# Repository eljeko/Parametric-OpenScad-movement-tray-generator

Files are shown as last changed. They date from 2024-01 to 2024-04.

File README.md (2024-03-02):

# Parametric OpenScad Movement tray generator
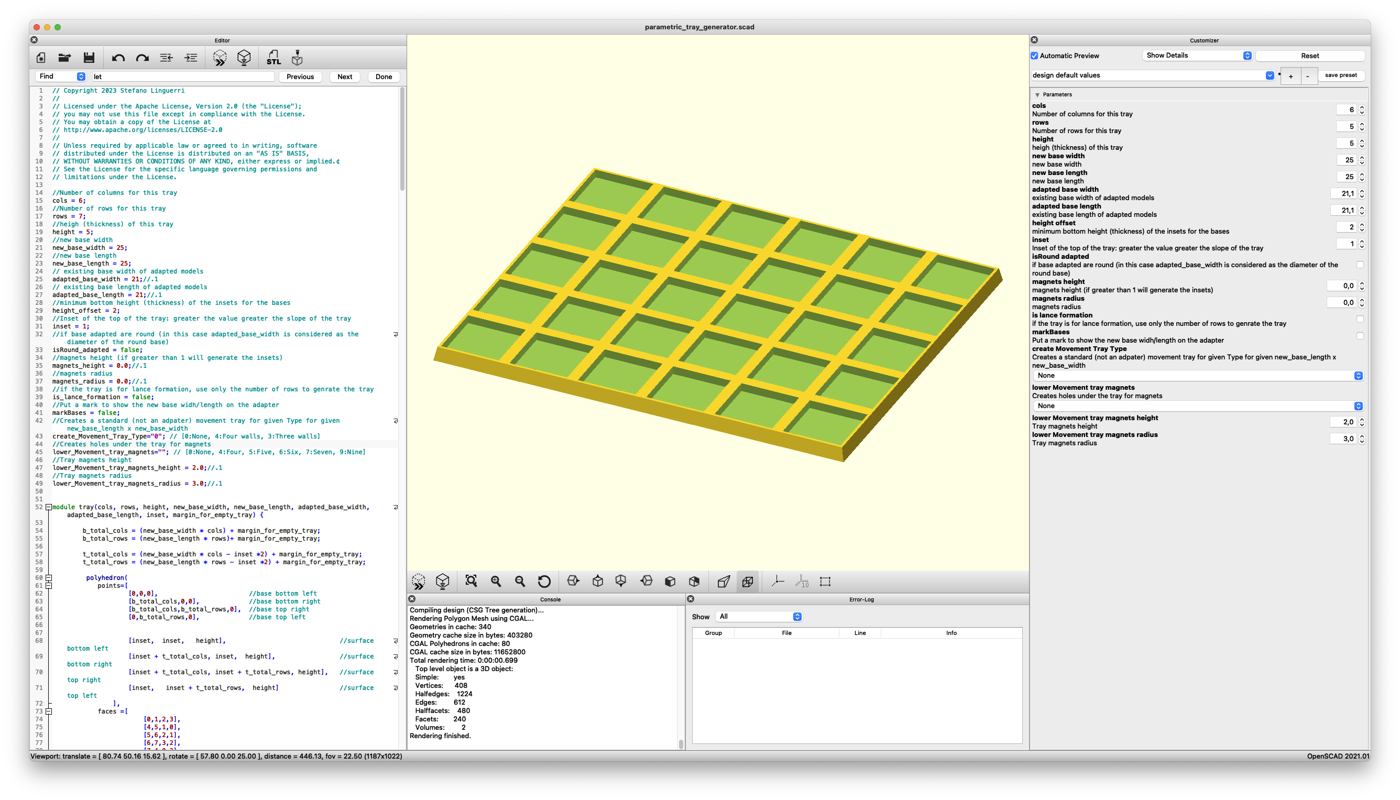
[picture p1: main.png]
Movement tray generator


This is an [OpenScad](http://openscad.org/index.html) script that can generate a movement tray to adapt the Old school warhammer 20mm square base to the new Old World 25mm square base system.

The script is absolutely parametric and can generate a custom tray for rows/cols tray.

I merged and enanched a new contribution with a script that can genrate bases plese follow the guide here [Parametric base generator](README_bases_generator.md)

# How to use

You can use the script and run it with [OpenScad](http://openscad.org/index.html) desktop app.

You can also generate trays from cli, for example this command:

```openscad -o tray.stl -D "cols=6;rows=3;" paremetric_tray_generator.scad```

Will generate a tray with 6 cols and 3 rows calculated for default 25mm square base and 20mm insets, the tray will be 150x75 mm.

The script can also generate a tray to adapt round bases setting ```isRound_adapted``` to true (default is false)

If you use different values for width and lenght you can generate also adapters for cavalry

# Important notes

## Tolerance 

When setting the value for ```adapted_base_width```and ```adapted_base_length``` add 1mm of tolerance eg: set 21mm for an old 20mm square base. The final "fit" depends also on you printer settings and calibration.  

### Parameters

```cols```  Number of columns for this tray

```rows``` Number of rows for this tray

```height``` heigh (thickness) of the tray

```new_base_width```  new base width 

```new_base_length```  new base length  

```adapted_base_width``` existing base width of adapted models

```adapted_base_length``` existing base length of adapted models

```height_offset``` minimum bottom height (thickness) of the insets for the bases

```inset``` Inset of the top of the tray: greater the value greater the slope of the tray

```isRound_adapted``` if base adapted are round (in this case adapted_base_size is considered as the diameter of the round base)

```magnets_height``` magnets height (if greater than zero will generate the insets)

```magnets_radius``` magnets radius

```isLanceFormation``` if the tray is for lance formation, use only the number of ```rows``` to genrate the tray

```createEmptyMovementTray``` Create a standard (non an adpater) movement tray for given new_base_length x new_base_width

```markBases``` Put a mark to show the new base widh/length on the adapter

## What you can do with the script

[Here](parametric_tray_generator.json) you can find a paremetric saved profiles file for openscad: place it in the same folder where you use the script, then you should see a list of profiles:

<img src="profiles.png" alt= profiles width="400" >

### Square 20mm to 25mm sample:

<img src="sample_tray.png" alt= “square” width="400" >

### Round 25mm to 25mm sample:

<img src="main_round_02.png" alt= “round” width="600" >

### Rectangular 25x50mm to 30x60mm sample:

<img src="rectangular.png" alt= “cavalry” width="600" >

### Adapter with marked bases to identify better minis contact in combat

<img src="marked_base.png" alt="marked_base" width="600" >

<img src="marked_base_02.png" alt="marked_base_02" width="600" >

### Holed tray

This is particularly useful to glue a metal plate under the tray to use magnetized minis

To obtain it just use a negative number for ```height_offset``` like -1

<img src="holed.png" alt=“holed” width="600" >

### Magnets 3x1mm insets

<img src="magnets.png" alt= “magnets” width="600" >

### Lance Formation

<img src="lance.png" alt= “lance” width="600" >

### Empty standard movement tray

With 3 walls

<img src="empty.png" alt= “standardmovement” width="600" >

With 4 walls

<img src="empty_4_walls.png" alt= “standardmovement” width="600" >

### Empty standard Lance movement tray

With 3 walls

<img src="lance_movement_standard.png" alt="lance_movement_standard" width="600" >

With 4 walls

<img src="empty_lance_4_walls.png" alt="lance_movement_standard" width="600" >

### Magnetized Tray (support for 4,5,7,9 magnets)

With ```lower_Movement_tray_magnets``` you can set the number of magnets holes to magnetize your tray/adapter for transportation

<img src="lower_magnets_5.png" alt="lower_magnets_5" width="600" >

<img src="lower_magnets_9.png" alt="lower_magnets_9" width="600" >

### One mini adapter

This example shows how to setup a single base adapter (remeber to add tolerance acconrding to your printer settings)

<img src="one_base_cavalry.png" alt="one_base_cavalry" width="600" >

## License

Parametric OpenScad movement tray generator is under [Apache 2
license](http://www.apache.org/licenses/LICENSE-2.0.html).

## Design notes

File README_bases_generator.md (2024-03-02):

# Parametric OpenScad Bases generator
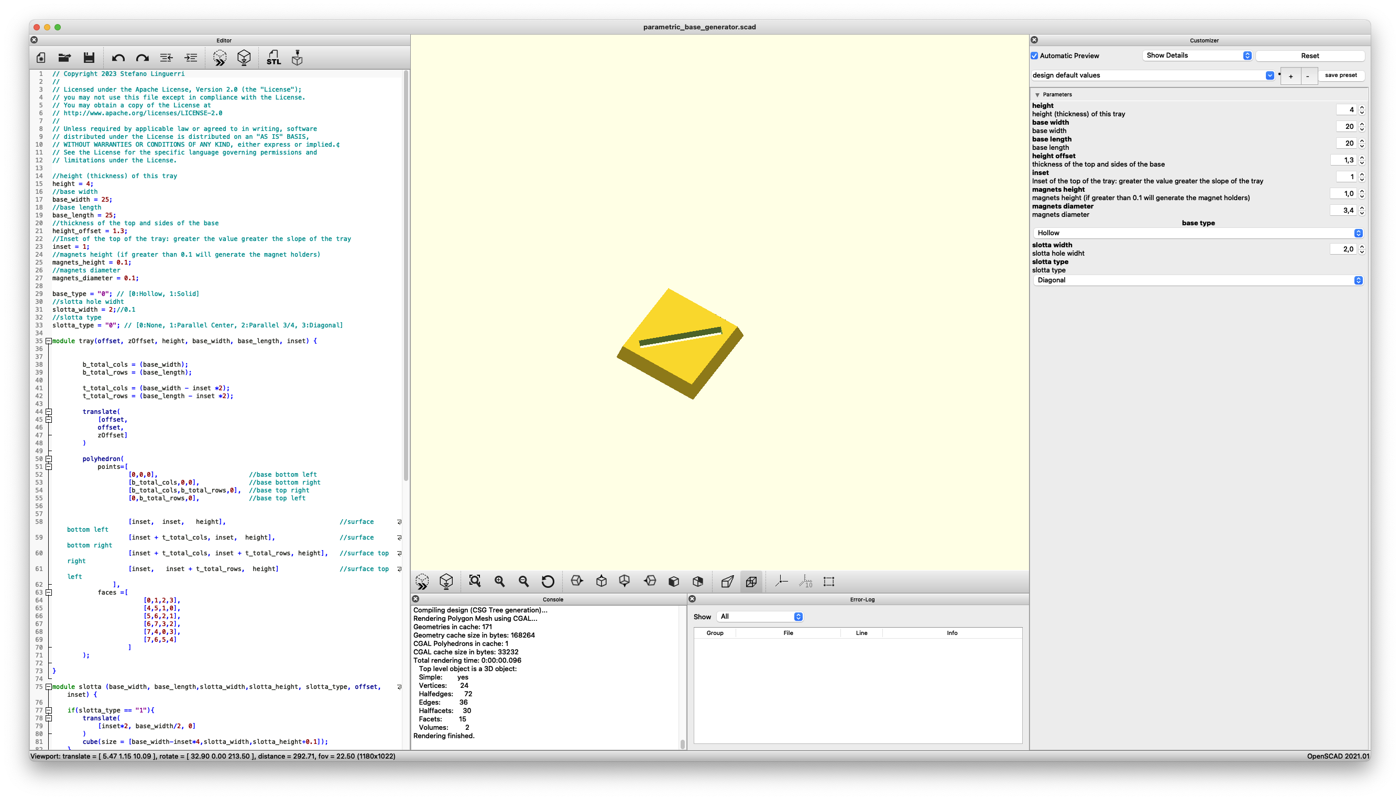
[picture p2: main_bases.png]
Bases generator


This is an [OpenScad](http://openscad.org/index.html) script that can generate square bases for Old school warhammer base system.

The script is absolutely parametric and can generate a custom square bases of any size (hollowed or solid) with slotta hole.

# Parameters

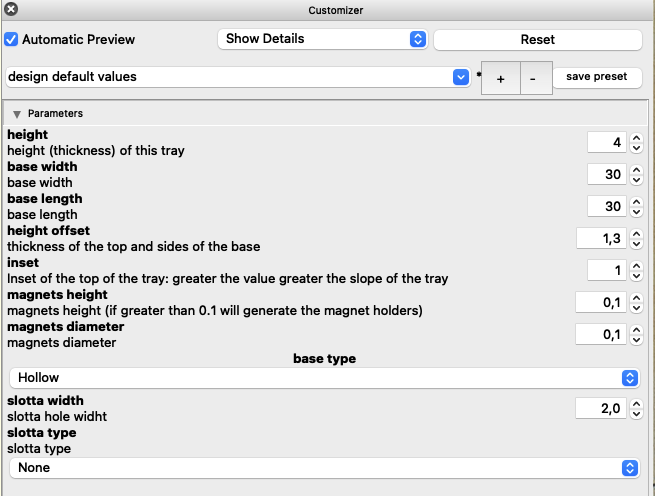
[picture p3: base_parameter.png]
parameter


## Some example 

Slotta

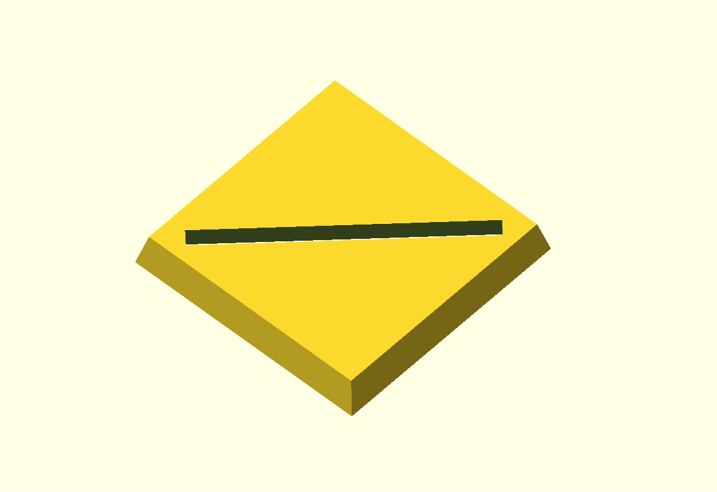
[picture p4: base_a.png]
base_a

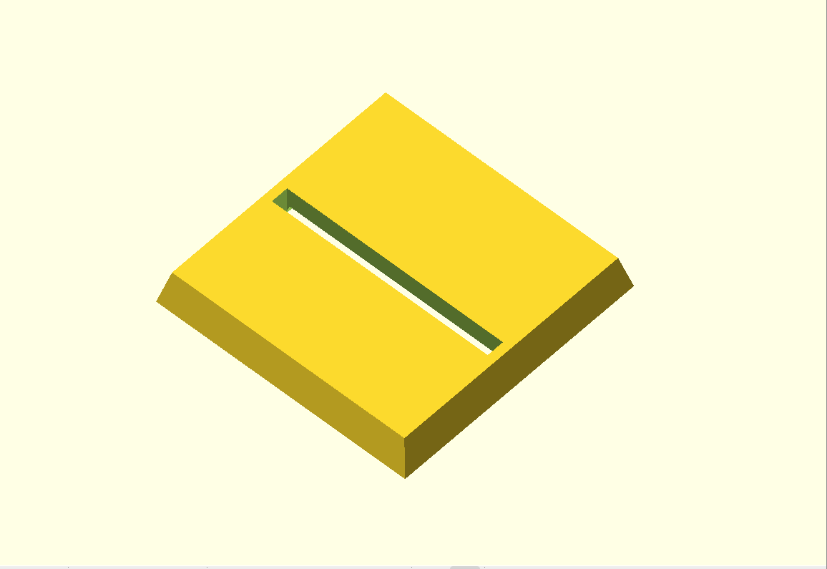
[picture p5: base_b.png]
base_b

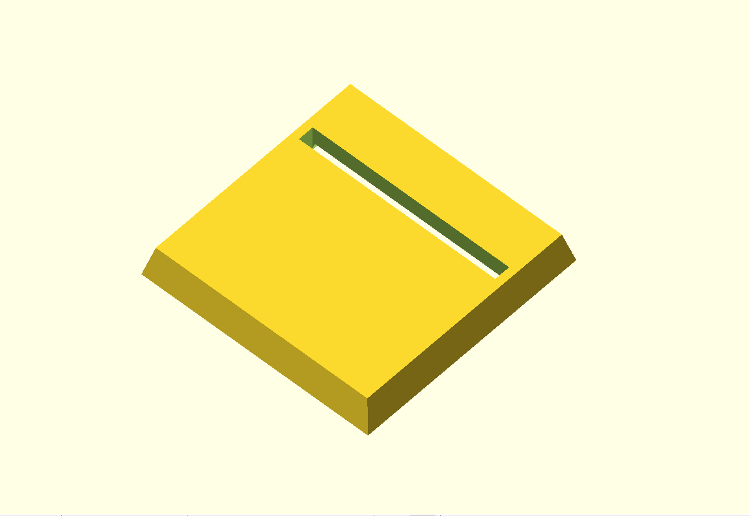
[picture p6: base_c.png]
base_c


Plain

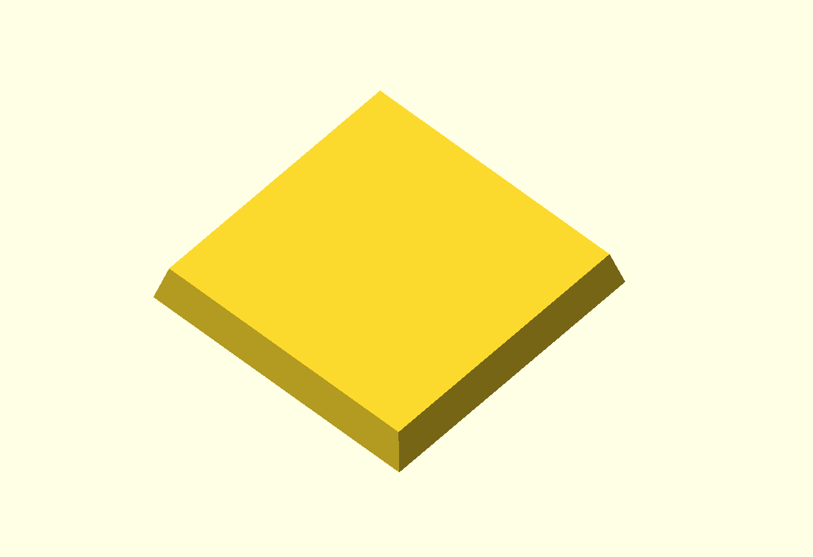
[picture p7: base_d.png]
base_d


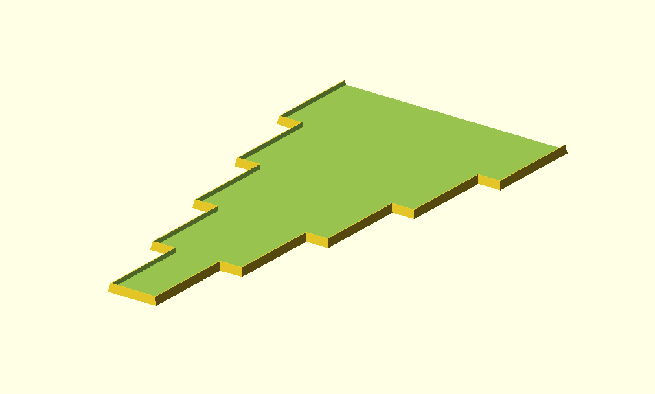
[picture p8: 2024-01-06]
lance_movement_standard.png

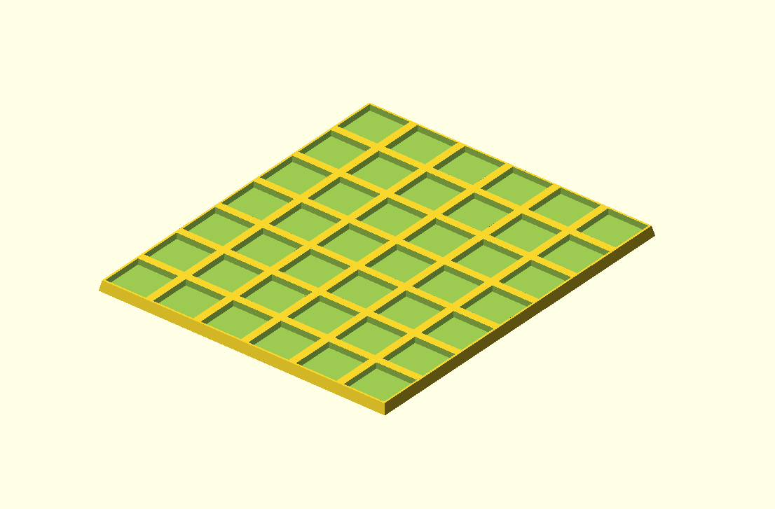
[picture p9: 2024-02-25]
sample_tray.png

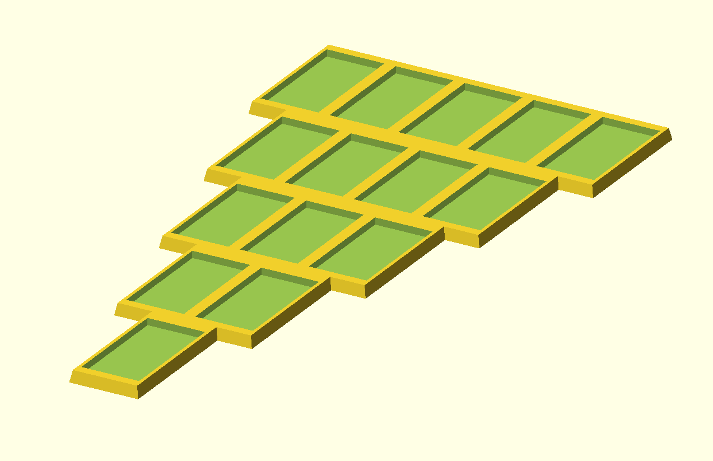
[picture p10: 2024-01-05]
lance.png

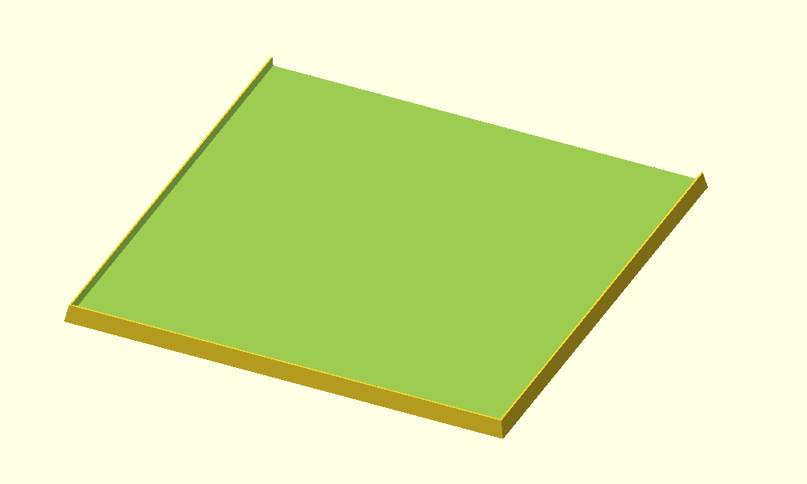
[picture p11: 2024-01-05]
empty.png

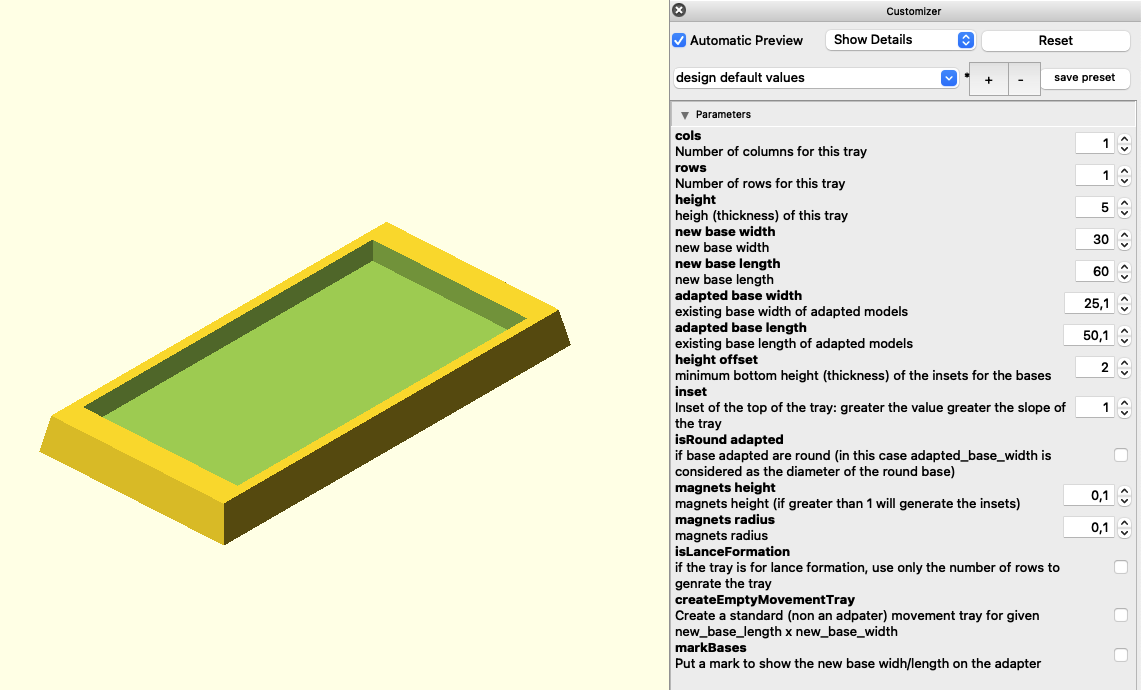
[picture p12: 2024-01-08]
one_base_cavalry.png

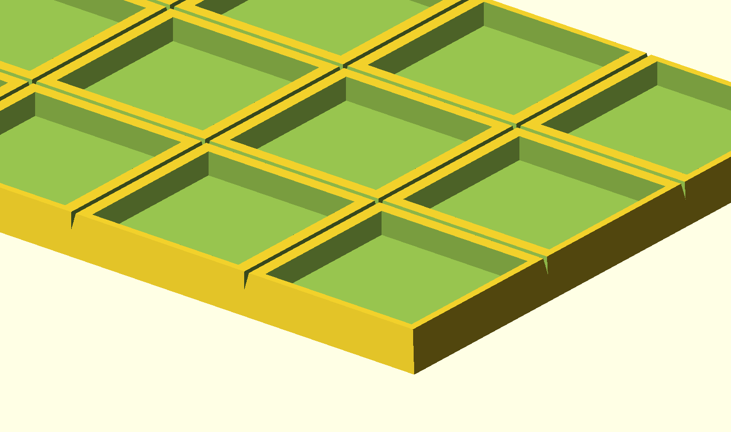
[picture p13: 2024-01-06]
marked_base_02.png

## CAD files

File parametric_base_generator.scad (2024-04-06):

// Copyright 2023 Stefano Linguerri
//
// Licensed under the Apache License, Version 2.0 (the "License");
// you may not use this file except in compliance with the License.
// You may obtain a copy of the License at
// http://www.apache.org/licenses/LICENSE-2.0
//
// Unless required by applicable law or agreed to in writing, software
// distributed under the License is distributed on an "AS IS" BASIS,
// WITHOUT WARRANTIES OR CONDITIONS OF ANY KIND, either express or implied.¢
// See the License for the specific language governing permissions and
// limitations under the License.

//height (thickness) of this tray
height = 4;//0.1
//base width 
base_width = 25;
//base length 
base_length = 25;
//thickness of the top and sides of the base
height_offset = 1.3;
//Inset of the top of the tray: greater the value greater the slope of the tray
inset = 1;
//magnets height (if greater than 0.1 will generate the magnet holders)
magnets_height = 0.1;
//magnets diameter
magnets_diameter = 0.1;

base_type = "0"; // [0:Hollow, 1:Solid]
//slotta hole width
slotta_width = 2;//0.1
//slotta hole length
slotta_length = 18;//0.1
//slotta type
slotta_type = "0"; // [0:None, 1:Parallel Center, 2:Parallel 3/4, 3:Diagonal]

module tray(offset, zOffset, height, base_width, base_length, inset) {
    
        
        b_total_cols = (base_width);
        b_total_rows = (base_length);
        
        t_total_cols = (base_width - inset *2);
        t_total_rows = (base_length - inset *2);
    
        translate(
            [offset,
            offset,
            zOffset]
        )

        polyhedron(
            points=[
                    [0,0,0],                        //base bottom left
                    [b_total_cols,0,0],             //base bottom right
                    [b_total_cols,b_total_rows,0],  //base top right
                    [0,b_total_rows,0],             //base top left


                    [inset,  inset,   height],                              //surface bottom left
                    [inset + t_total_cols, inset,  height],                 //surface bottom right
                    [inset + t_total_cols, inset + t_total_rows, height],   //surface top right
                    [inset,   inset + t_total_rows,  height]                //surface top left
                ],
            faces =[
                        [0,1,2,3],
                        [4,5,1,0],
                        [5,6,2,1],
                        [6,7,3,2],
                        [7,4,0,3],
                        [7,6,5,4]
                    ]
        ); 
           
}

module slotta (base_width, base_length,slotta_width,slotta_height, slotta_type, offset,inset) {   

    if(slotta_type == "1"){
        translate( 
            [(base_width - slotta_length)/2, base_width/2, -0.1]
        )
        cube(size = [slotta_length,slotta_width,slotta_height+0.2]);
    }
    
    if(slotta_type == "2"){
        translate( 
            [(base_width - slotta_length)/2, base_width/4, -0.1]
        )
        cube(size = [slotta_length,slotta_width,slotta_height+0.2]);
    }
    
    if(slotta_type == "3"){

        let(cathetus_slotta_width = slotta_width/sqrt(2),cathetus_slotta_lenght = slotta_length/sqrt(2)){
            echo(">>>>",cathetus_slotta_lenght)
            translate( 
                [(base_width/2)-(cathetus_slotta_lenght/2), (base_length/2) -(cathetus_slotta_lenght/2), -0.1]
            )

            rotate(45)

            cube(size = [slotta_length,slotta_width,slotta_height+0.2]);
                    
        }
    }    
}

module magnets_holes (base_width, base_length, magnets_height, magnets_diameter) {   
    translate( 
        [base_width/2,
        base_length/2, 
        -0.1]
    )
    cylinder(d = magnets_diameter, h = magnets_height+0.01,$fn=30);
}

difference(){  
    
    color ([0.5, 0.5, 0.5]) {
        tray(0,0, height, base_width, base_length, inset);
    }
    
    if(base_type == "0"){
        color ([0.7, 0.7, 0.7]) {                   
            tray(height_offset, -1.0, height - height_offset, base_width - (2*height_offset), base_length - (2 * height_offset), inset);
        }   
    }
    
    if (magnets_height > 0.1){     
        magnets_holes (base_width, base_length, magnets_height, magnets_diameter);            
    }
    
    slotta(base_width,base_length,slotta_width,height,slotta_type,height_offset,inset);

}

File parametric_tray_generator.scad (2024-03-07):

// Copyright 2023 Stefano Linguerri
//
// Licensed under the Apache License, Version 2.0 (the "License");
// you may not use this file except in compliance with the License.
// You may obtain a copy of the License at
// http://www.apache.org/licenses/LICENSE-2.0
//
// Unless required by applicable law or agreed to in writing, software
// distributed under the License is distributed on an "AS IS" BASIS,
// WITHOUT WARRANTIES OR CONDITIONS OF ANY KIND, either express or implied.¢
// See the License for the specific language governing permissions and
// limitations under the License.

//Number of columns for this tray
cols = 6;
//Number of rows for this tray
rows = 7;
//heigh (thickness) of this tray
height = 5;//.1
//new base width 
new_base_width = 25;
//new base length 
new_base_length = 25;
// existing base width of adapted models
adapted_base_width = 21;//.1
// existing base length of adapted models
adapted_base_length = 21;//.1
//minimum bottom height (thickness) of the insets for the bases
height_offset = 2;
//Inset of the top of the tray: greater the value greater the slope of the tray
inset = 1;
//if base adapted are round (in this case adapted_base_width is considered as the diameter of the round base)
isRound_adapted = false;
//magnets height (if greater than 1 will generate the insets)
magnets_height = 0.0;//.1
//magnets radius
magnets_radius = 0.0;//.1
//if the tray is for lance formation, use only the number of rows to genrate the tray
is_lance_formation = false;
//Put a mark to show the new base widh/length on the adapter
markBases = false;
//Creates a standard (not an adpater) movement tray for given Type for given new_base_length x new_base_width 
create_Movement_Tray_Type="0"; // [0:None, 4:Four walls, 3:Three walls]
//Creates holes under the tray for magnets
lower_Movement_tray_magnets="0"; // [0:None, 4:Four, 5:Five, 6:Six, 7:Seven, 9:Nine]
//Tray magnets height
lower_Movement_tray_magnets_height = 2.0;//.1
//Tray magnets radius
lower_Movement_tray_magnets_radius = 3.0;//.1


module tray(cols, rows, height, new_base_width, new_base_length, adapted_base_width, adapted_base_length, inset, margin_for_empty_tray) {
    
        b_total_cols = (new_base_width * cols) + margin_for_empty_tray;
        b_total_rows = (new_base_length * rows)+ margin_for_empty_tray;
        
        t_total_cols = (new_base_width * cols - inset *2) + margin_for_empty_tray;
        t_total_rows = (new_base_length * rows - inset *2) + margin_for_empty_tray;
        
         polyhedron(
            points=[
                    [0,0,0],                        //base bottom left
                    [b_total_cols,0,0],             //base bottom right
                    [b_total_cols,b_total_rows,0],  //base top right
                    [0,b_total_rows,0],             //base top left
        

                    [inset,  inset,   height],                              //surface bottom left
                    [inset + t_total_cols, inset,  height],                 //surface bottom right
                    [inset + t_total_cols, inset + t_total_rows, height],   //surface top right
                    [inset,   inset + t_total_rows,  height]                //surface top left
                ],
            faces =[
                        [0,1,2,3],
                        [4,5,1,0],
                        [5,6,2,1],
                        [6,7,3,2],
                        [7,4,0,3],
                        [7,6,5,4]
                    ]
        ); 
   
}

//this module will create the hole in the "empty" classic movement tray
module empty_tray_hole(cols, rows, height_offset, new_base_width,  new_base_length, adapted_base_width, adapted_base_length, inset, margin_for_empty_tray,create_Movement_Tray_Type) {
    
    t_total_cols = (new_base_width * cols ) ;
    t_total_rows = (new_base_length * rows);

 
    translate( 
                [margin_for_empty_tray/2, //row
               margin_for_empty_tray/2, //col
                height_offset]
    )                       

    if(create_Movement_Tray_Type == "3"){
        cube([t_total_cols,t_total_rows+margin_for_empty_tray, 30]);            
    }else{
        cube([t_total_cols,t_total_rows, 30]);            
    }    
}

module adapted_base_holes(cols, rows, height_offset, new_base_width,  new_base_length, adapted_base_width, adapted_base_length) {
    
    gap_w = new_base_width - adapted_base_width;
    gap_l = new_base_length - adapted_base_length;

    for (c = [0:cols-1]){
        for (r = [0:rows-1]){
           translate( 
                        [gap_w/2 + (c*adapted_base_width) + (c*gap_w), //row
                        gap_l/2 + (r*adapted_base_length) + (r*gap_l), //col
                        height_offset]
            )                       
            cube([adapted_base_width,adapted_base_length, 30]);
            
        }
    }
}

module adapted_base_holes_round(cols, rows, height_offset, new_base_width, new_base_length, adapted_base_width, adapted_base_length) {
    
    for (c = [0:cols-1]){
        for (r = [0:rows-1]){
            translate( 
                        [new_base_width/2 + new_base_width * c , //row
                        new_base_length/2 + new_base_length * r, //col
                        height_offset]
            )
            //resize([adapted_base_width,adapted_base_length]) 
            cylinder(r = adapted_base_width/2, h = height);
           
        }
    }
}

module magnets_holes (cols, rows,  new_base_width, new_base_length, magnets_height, magnets_radius, height, height_offset) {
    
    for (c = [0:cols-1]){
        for (r = [0:rows-1]){
            translate( 
                        [new_base_width/2 + new_base_width * c , //row
                        new_base_length/2 + new_base_length * r, //col
                        height_offset-magnets_height+0.01]
            )
            cylinder(r = magnets_radius/2, h = magnets_height+0.01,$fn=20);
           
        }
    }
}

/// BASE MARKER
module mark_new_bases (cols, rows,  new_base_width, new_base_length, magnets_height, magnets_radius, height, height_offset) {
    color ([0.9, 0.4, 0.4])
                    {
        for (c = [1:cols-1]){
            translate( 
                [new_base_width * c-inset/2 , //col
                 new_base_length * 0, //row
                 height+height/5]
            )

            rotate([-90,0,0]) {             
                linear_extrude(new_base_length*rows) {
                     polygon(points=[[0,0],[1,0],[inset/2,(height-height_offset)]], paths=[[0,1,2]]);
                }
            }           
        }
        
        
        for (r = [1:rows-1]){
            translate( 
                    [new_base_width * 0 , //col
                     new_base_length * r-inset/2, //row
                     height+height/5]
            )
            rotate([90,90,90]) { 
                linear_extrude(new_base_width*cols) {
                    polygon(points=[[0,1],[(height-height_offset),inset/2],[0,0]], paths=[[0,1,2]]);
                }
            }
        }
    }
}

module lance_formation (cols, rows,  new_base_width, new_base_length, magnets_height, magnets_radius, height, height_offset,  inset, margin_for_empty_tray) {
    
    
    for (thisRow = [0:rows-1]){    

        translate( [0,thisRow*new_base_length,0]){
            for (thisCol = [0:thisRow]){    
                translate( [(new_base_width/2)*thisRow-(new_base_width*thisCol),0,0]){
                    //color([0.4, rands(0.01, 1,1)[0],rands(0.01, 1,1)[0] ])
                    color ([0.5, 0.5, 0.5])
                    {
                        lance_sloped_slot(thisCol+1, thisRow+1 == rows, height, new_base_width, new_base_length, adapted_base_width, adapted_base_length, inset, margin_for_empty_tray);
                    }    
                }
            }
        }
    }     
}

////////////////////////////////
// LANCE FORMATION            //
////////////////////////////////
module lance_sloped_slot(cols, isLastRow, height, new_base_width, new_base_length, adapted_base_width, adapted_base_length, inset, margin_for_empty_tray) {
    
        rows = 1;
    
        b_total_cols = (new_base_width * cols) + margin_for_empty_tray;
        b_total_rows = (new_base_length * rows)+ margin_for_empty_tray;
        
        t_total_cols = (new_base_width * cols - inset *2) + margin_for_empty_tray;
        t_total_rows = (new_base_length * rows - inset *2) + margin_for_empty_tray;
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

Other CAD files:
bases.scad
paremetric_tray_generator.scad

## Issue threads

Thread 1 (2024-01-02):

Feature Requests - Cavalry Bases & Magenet Insets

DaytonEclipse, 2024-01-02:
Hey,

First off this is brilliant and works like a charm.  I'm going to be printing some starting tomorrow to rank up my gobbos & dwarves.

I have a couplle of features requests to run by you and see if they could in any way be accomodated.

1) Cavalry bases will undergo similar resizings with 25x50 becoming 30x60.  Is it possible to get a version to cover cavalry?  Also asking if the cavalry one could allow from straight ranking or the tapered style like this:
      [GS World 180x90mm](https://www.greenstuffworld.com/en/warhammer-old-world-bases/3422-mdf-movement-trays-old-world-180x90mm-1x2x3.html)

2) Is it possible to include a parameter than enables the inset of a magnet in the centre of each troop hole to allow for magnetisation.  The goto magnet seems to be 3x1mm's, but a parameter that could allow for different sizes would be awesome..

Thanks for considering and understand if you're not able to accomodate.

eljeko, 2024-01-03:
@DaytonEclipse I close this for now, if you want please follow the three different issues I opened.

Thank you

DaytonEclipse, 2024-01-04:
Thank you so much for considering and then actioning these.  Amazing work!

Closed 2024-01-03.

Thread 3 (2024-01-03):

Magnets Insets

eljeko, 2024-01-03:
Magnets Insets support at the center of the each slot

_"Is it possible to include a parameter than enables the inset of a magnet in the centre of each troop hole to allow for magnetisation. The goto magnet seems to be 3x1mm's, but a parameter that could allow for different sizes would be awesome.."_

Closed 2024-01-03.

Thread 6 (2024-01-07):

Allow tweaking of magnet sizes

kayti-wow, 2024-01-07:
The magnet parameters currently only allow integers when working in the Customization window of OpenSCAD.  However - just like the adapted base size parameters - it is necessary to allow for decimals so that we can compensate for geometric accuracy on our own printers and nozzle sizes.

On my printer 3 is too small for a 3mm magnet, while 4 is too big.

Closed 2024-01-08.

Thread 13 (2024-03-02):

Outer wall thickness

steventroughtonsmith, 2024-03-02:
It would be nice to be able to specify the outer wall thickness when creating the standard (non-adapter) movement tray types. As it is, the wall thickness is a byproduct of the slope from the bottom vertices to the top ones, which makes it difficult to tweak independently — and the default is much thinner than a GW movement tray, for example, if you're trying to match the look across your army between printed and non-printed trays.

I couldn't figure this out myself, but if you're open to enhancement requests this would be pretty neat ✌️

eljeko, 2024-03-03:
I'll work on this

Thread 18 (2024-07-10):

Cut big trays in pieces.

zastiu, 2024-07-10:
I want to print a 6x6 adapter but it takes 6-7 hours to print. It could be interesting to print 4 pieces of 3x3 and then glue it or put a magnet.

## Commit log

2023-04-15 Create paremetric_tray_generator.scad
    First release
    [paremetric_tray_generator.scad]
2023-04-15 Updated license
    [paremetric_tray_generator.scad]
2023-04-17 Updated default value for adapted_base_size to 21
    [paremetric_tray_generator.scad]
2024-01-03 Support for Cavalry Bases close #2
    [paremetric_tray_generator.scad]
2024-01-03 typo fix
    [paremetric_tray_generator.scad]
2024-01-03 support for magnets insets closes #3
    [paremetric_tray_generator.scad]
2024-01-04 Lance tray support closes #4
    [paremetric_tray_generator.scad]
2024-01-05 Slope and magnets for Lance formation closes #5
    [paremetric_tray_generator.scad]
2024-01-06 Empty tray for Lance formation and profiles
    [paremetric_tray_generator.scad]
2024-01-06 Support for marked bases
    [paremetric_tray_generator.scad]
2024-01-08 Added tolerance with decimal to magnets insets and fixed typo in filename. closes #6
    [parametric_tray_generator.scad]
2024-01-19 fix #7
    [parametric_tray_generator.scad]
2024-01-24 Add the ability to generate bases of any shape and size, with optional magnet holders
    [bases.scad]
2024-01-26 Add missing 20mm base size
2024-02-25 Option for rear wall in empty tray closes #11
    [parametric_tray_generator.scad]
2024-02-25 Doc and profiles update
    [parametric_tray_generator.scad]
2024-03-02 Movment tray lower magnets closes #8
    [parametric_tray_generator.scad]
2024-03-02 Update docs and typos fix
    [parametric_tray_generator.scad]
2024-03-02 Base generator merge
    [parametric_base_generator.scad]
2024-03-02 Base generator
    [parametric_base_generator.scad]
2024-03-05 :adhesive_bandage:changed height resolutio to 0.1mm
    [parametric_base_generator.scad, parametric_tray_generator.scad]
2024-03-12 :sparkles: adds variable slotta length for parallel slotta
    [parametric_base_generator.scad]
2024-03-12 :bug: fixed centering of slottas
    [parametric_base_generator.scad]
2024-03-12 :bug: put 0.1 height resolution back in
    [parametric_base_generator.scad]
2024-04-06 Parametric slotta length (also on diagonal) closes #14
    [parametric_base_generator.scad]
